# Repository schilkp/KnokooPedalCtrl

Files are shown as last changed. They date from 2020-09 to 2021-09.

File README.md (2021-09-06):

# KnokooPedalCtrl

A small modification that allows the Knokoo FES150 Fume Extractor to be turned on
and off using a 1/4" foot pedal.

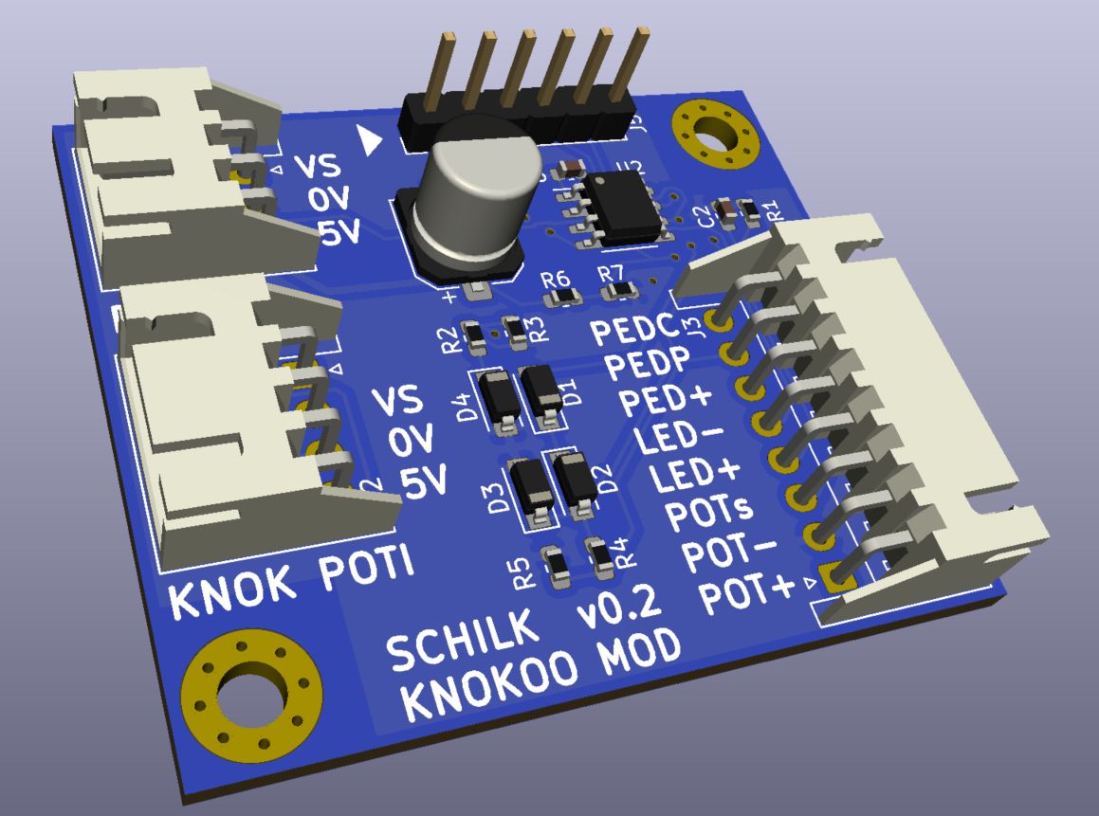
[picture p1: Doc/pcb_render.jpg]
PCB render


## Why?

The way my bench is setup, I cannot comfortably reach the speed control/power knob.
Life's very difficult, tell me about it. 

But because I know myself well enough to know that I won't use this (or any) fume extractor
if I have to crawl on the floor every time I want to solder something, this small project
was born.

It is also not the quietest machine, so being able to turn it on and off only when actually 
soldering has made using it much more pleasant. 

## How?

This small PIC12F1572-based board sits between the Knokoo's Main PCB and the front intensity knob.  

The Knokoo turns itself off when the intensity knob is turned all the way off.
This board interrupts the 5V rail normally provided to the potentiometer by the Knokoo PCB, and only
enables it when the foot pedal is pressed.

This way the Intensity Knob can permanently be left set to the desired intensity, and the pedal can
be used to turn the unit on and off. 

Pressing the pedal once turns the unit on and starts a timer controlled by the position of a second
potentiometer. The unit will shut off when either the timer runs out or the pedal is pressed again.

Pressing the pedal twice in short succession turns the unit on permanently until the pedal is pressed
again.

If the pedal is unplugged, the board will disable itself and the unit will function as before.

## Installation

[will follow shortly]

## Slight Modifications

### No Timer Potentiometer

Instead of a second potentiometer, the timer duration can also be permanently fixed using resistors R6 and R7.  

The duration will be approx `(15)*(R6/(R6+R7)` minutes

(R6+R7) should be 10K at least. The pins where the potentiometer would otherwise be connected to should be left disconnected.

### No Pedal Detect

If the jack for the pedal does not have a switch, PEDC should be connected to GND (for example to POT-).

Of course, in this case, the unit will not return to normal operation when no pedal is connected.

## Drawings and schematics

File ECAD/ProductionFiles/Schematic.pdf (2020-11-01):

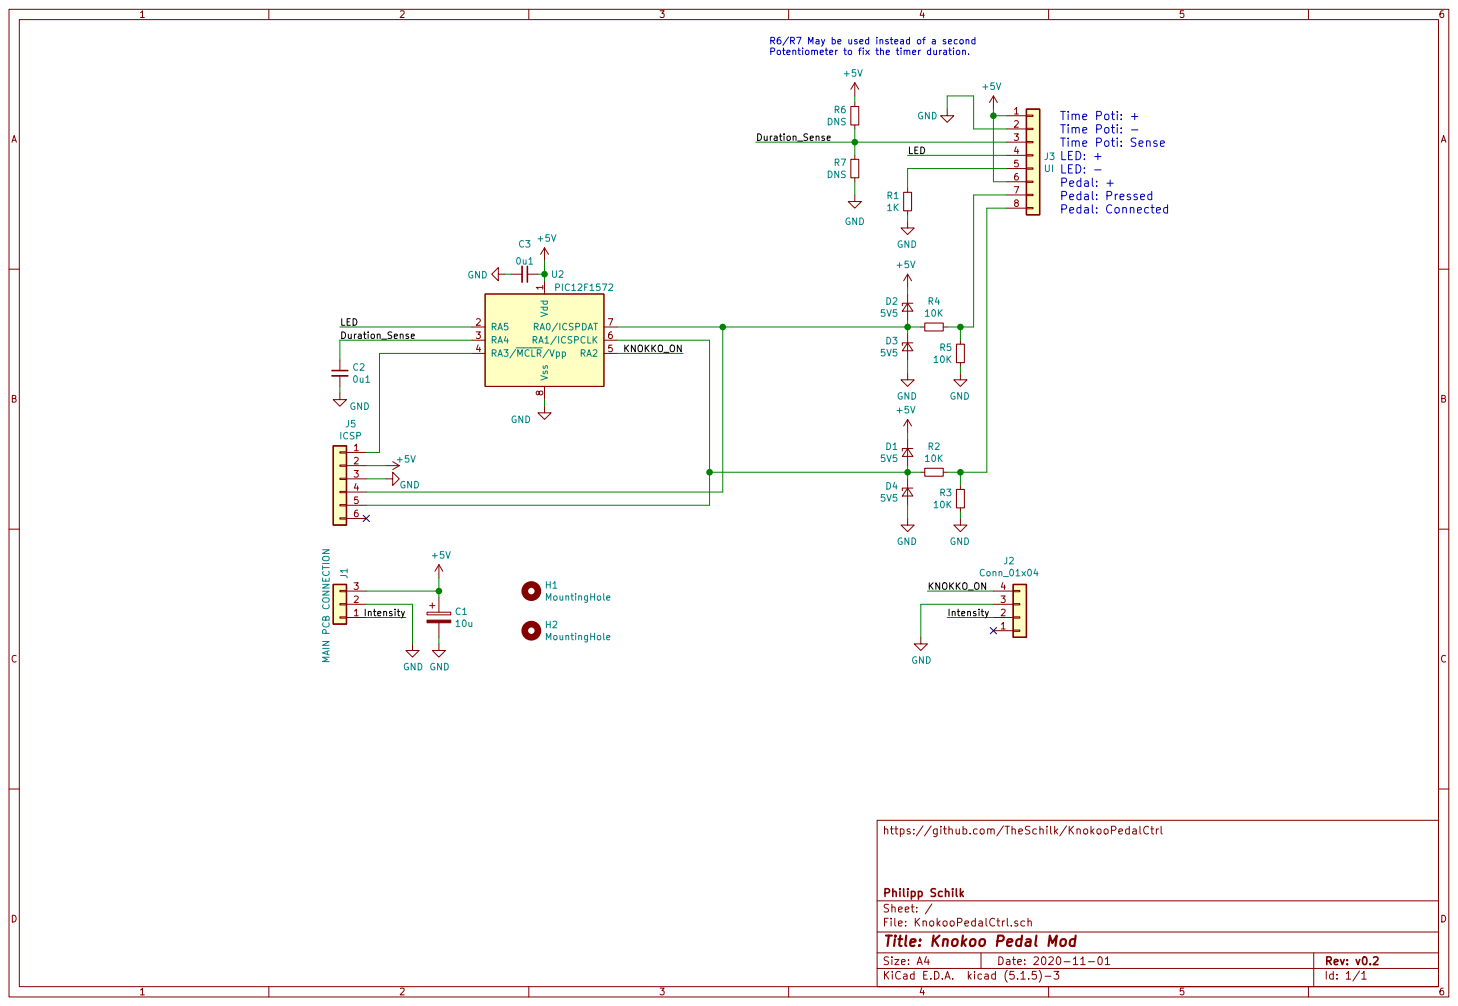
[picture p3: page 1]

https://github.com/TheSchilk/KnokooPedalCtrl

File: KnokooPedalCtrl.sch Sheet: / Philipp Schilk

Id: 1/1 Title: Knokoo Pedal Mod

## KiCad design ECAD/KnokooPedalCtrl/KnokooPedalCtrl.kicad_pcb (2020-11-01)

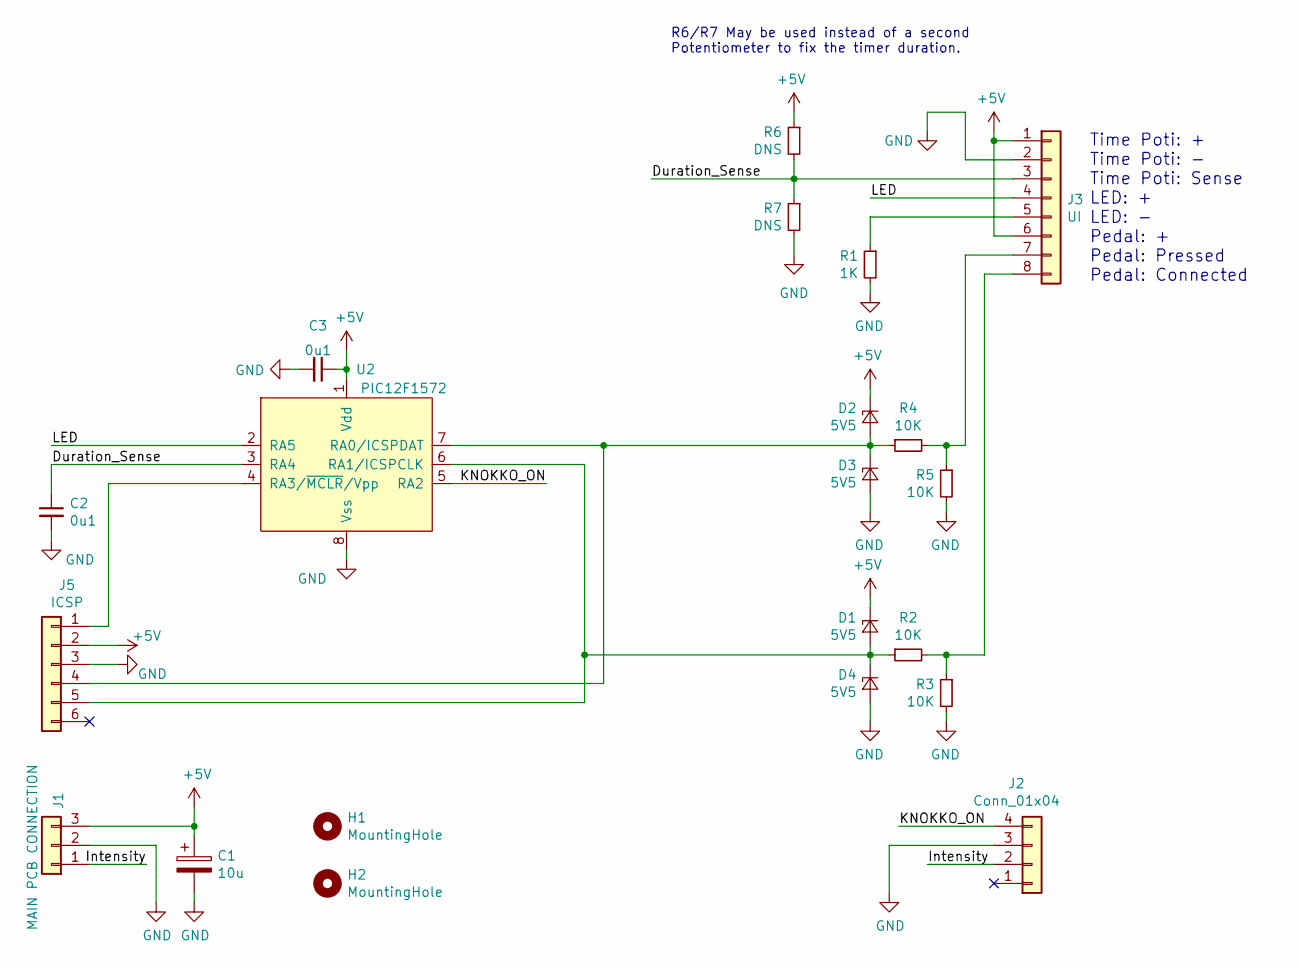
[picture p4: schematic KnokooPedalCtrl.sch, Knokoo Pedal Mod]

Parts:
C1: 10u; CP_Elec_6.3x7.7
C2, C3: 0u1; C_0603_1608Metric
D1, D2, D3, D4: 5V5; D_SOD-123
H1, H2: MountingHole; MountingHole_3.2mm_M3_Pad_Via
J1: MAIN PCB CONNECTION; JST_XH_S3B-XH-A_1x03_P2.50mm_Horizontal
J2: Conn_01x04; JST_XH_S4B-XH-A_1x04_P2.50mm_Horizontal
J3: UI; JST_XH_S8B-XH-A_1x08_P2.50mm_Horizontal
J5: ICSP; PinHeader_1x06_P2.54mm_Vertical
R1: 1K; R_0603_1608Metric
R2, R3, R4, R5: 10K; R_0603_1608Metric
R6, R7: DNS; R_0603_1608Metric
U2: PIC12F1572; SOIC-8_3.9x4.9mm_P1.27mm

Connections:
+5V: C1.1, C3.1, D1.1 (K), D2.1 (K), J1.3, J3.1, J3.6, J5.2, R6.1, U2.1 (Vdd)
/Duration_Sense: C2.1, J3.3, R6.2, R7.1, U2.3 (RA4)
/Intensity: J1.1, J2.2
/KNOKKO_ON: J2.4, U2.5 (RA2)
/LED: J3.4, U2.2 (RA5)
GND: C1.2, C2.2, C3.2, D3.2 (A), D4.2 (A), J1.2, J2.3, J3.2, J5.3, R1.2, R3.2, R5.2, R7.2, U2.8 (Vss)
unnamed: D1.2 (A), D4.1 (K), J5.5, R2.1, U2.6 (RA1/ICSPCLK)
unnamed: D2.2 (A), D3.1 (K), J5.4, R4.1, U2.7 (RA0/ICSPDAT)
unnamed: J3.5, R1.1
unnamed: J3.7, R4.2, R5.1
unnamed: J3.8, R2.2, R3.1
unnamed: J5.1, U2.4 (RA3/~MCLR~/Vpp)

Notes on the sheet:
Time Poti: + Time Poti: - Time Poti: Sense LED: + LED: - Pedal: + Pedal: Pressed Pedal: Connected
R6/R7 May be used instead of a second Potentiometer to fix the timer duration.

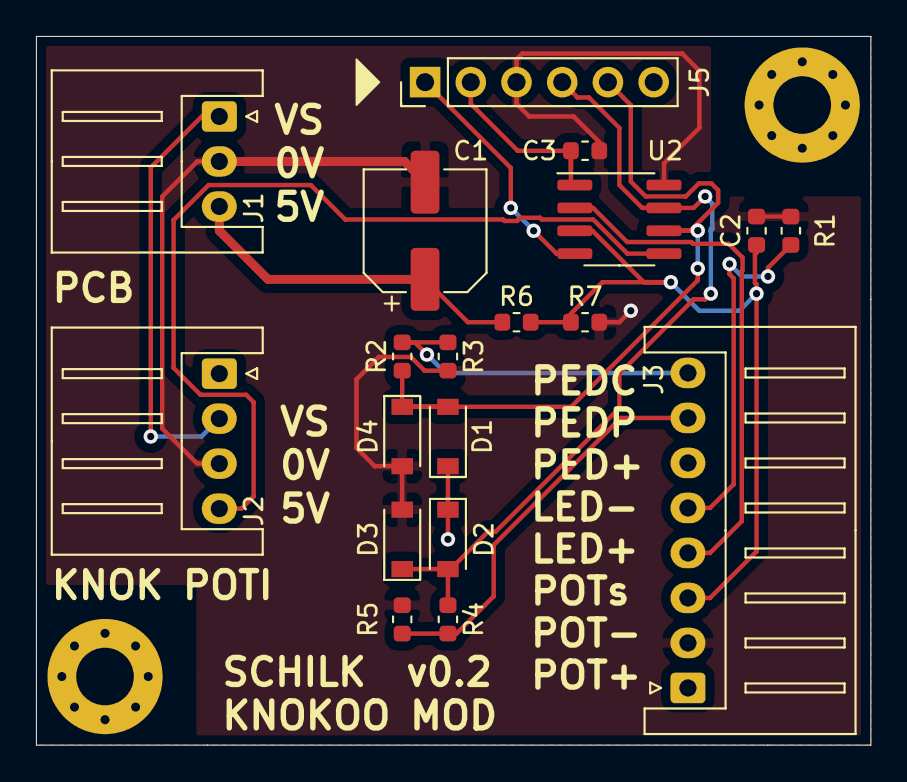
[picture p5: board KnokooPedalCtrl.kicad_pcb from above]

Board: 2 copper layers, 46.4 x 39.4 mm, 21 parts (0 on the bottom side), 12 nets.

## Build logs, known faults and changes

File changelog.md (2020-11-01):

# v0.2
  - Fixed Silkscreen of Poti Connector...
  - Added Resistors to bypass second potentiometer

# v0.1
  - Fixed pinorder of Knokoo Poti Connector
  - Fixed Silkscreen of PCB Connector

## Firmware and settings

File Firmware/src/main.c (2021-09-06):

// =================================================================
//                  Knokoo FES150 Pedal Control
//                      PIC12F1572 Firmware
//                      Philipp Schilk 2020
//
// This was written fairly quickly without much second thought.
// Please don't look to closely.
// =================================================================


// ======== PIC Fuses ==========================================================

// CONFIG1
#pragma config FOSC = INTOSC    // (INTOSC oscillator; I/O function on CLKIN pin)
#pragma config WDTE = ON        // Watchdog Timer Enable (WDT enabled)
#pragma config PWRTE = OFF      // Power-up Timer Enable (PWRT disabled)
#pragma config MCLRE = ON       // MCLR Pin Function Select (MCLR/VPP pin function is MCLR)
#pragma config CP = OFF         // Flash Program Memory Code Protection (Program memory code protection is disabled)
#pragma config BOREN = ON       // Brown-out Reset Enable (Brown-out Reset enabled)
#pragma config CLKOUTEN = OFF   // Clock Out Enable (CLKOUT function is disabled. I/O or oscillator function on the CLKOUT pin)

// CONFIG2
#pragma config WRT = OFF        // Flash Memory Self-Write Protection (Write protection off)
#pragma config PLLEN = OFF      // PLL Enable (4x PLL disabled)
#pragma config STVREN = ON      // Stack Overflow/Underflow Reset Enable (Stack Overflow or Underflow will cause a Reset)
#pragma config BORV = LO        // Brown-out Reset Voltage Selection (Brown-out Reset Voltage (Vbor), low trip point selected.)
#pragma config LPBOREN = OFF    // Low Power Brown-out Reset enable bit (LPBOR is disabled)
#pragma config LVP = ON         // Low-Voltage Programming Enable (Low-voltage programming enabled)


// ======== Config =============================================================

#define DEBOUNCE_TIME  25  // Time inputs are ignored after input in 10s of ms
#define DBLPRESS_TIME  400 // Max interval to count as 'double press' in 10s of ms
#define BLINK_TIME     100 // LED Blink period in 10s of ms

// Coefficients to determine min and max length:
// Min length in seconds: ADCSCALE_BASE / 100
// Max length in seconds: (ADCSCALE_BASE + ADCSCALE_MULT*2^10) / 100
#define ADCSCALE_MULT 90
#define ADCSCALE_BASE 12000

// ======== Code ===============================================================

#include <pic.h>
#include <stdint.h>

uint32_t debounce_count;
uint8_t debounce_prevstate;

uint32_t on_timer;
uint32_t press_timer;

uint32_t blink_timer;
uint8_t  blink_state;

uint32_t result;

typedef enum{
    state_off,
    state_timer,
    state_on         
}STATE_T;

STATE_T state;

int main(int argc, char** argv) {
    CLRWDT();
    
    // ===== WDT & CLK =====
    // Using internal MF OSC at 500khz
    OSCCONbits.SPLLEN = 0;
    OSCCONbits.IRCF = 0b0111;
    OSCCONbits.SCS = 0b10;
    
    // Have WDT reset every 512ms
    WDTCONbits.WDTPS = 0b01001;
    
    // ===== Config GPIO =====
    TRISAbits.TRISA0 = 1; // Pedal Input
    TRISAbits.TRISA1 = 1; // Pedal Sense Input
    TRISAbits.TRISA2 = 0; // KNOKOO Ouput
    TRISAbits.TRISA4 = 1; // Poti Input
    TRISAbits.TRISA5 = 0; // LED Output
    
    // Clear all outputs
    LATA = 0x0; 
    
    // Set RA4 as only analog input
    ANSELA = 0x0;
    ANSELAbits.ANSA4 = 1;
    
    // Disable all pullups, all pins push-pull,
    // no slewrate limiting
    WPUA = 0x0;
    ODCONA = 0x0;
    SLRCONA = 0x0;
    
    // ===== Config ADC ======
    ADCON0bits.CHS = 0b00011; // Select CH3 (RA4)
    
    ADCON1bits.ADFM = 1; // Right-justified result
    ADCON1bits.ADCS = 0b000; // Conversion Clk Fosc/2
    ADCON1bits.ADPREF = 0b00; // VDD is positive voltage refernce
    
    ADCON2bits.TRIGSEL = 0; // No Automatic triggering
    
    ADCON0bits.ADON = 1; // Turn on ADC
    
    ADCON0bits.GO = 1; // Start conversion
    
    // ===== Setup Variables =====
    debounce_count = 0;
    debounce_prevstate = PORTAbits.RA0;
    state = state_off;
    blink_state = 0;
    
    // ===== Config Regular interrupt =====
    // Setup Timer 0 to overflow at aprox. 120Hz and trigger interrupt
    OPTION_REGbits.TMR0CS = 0; // Timer 0 clocked from Fosc/4
    OPTION_REGbits.PSA = 0;    // Timer 0 has prescalar
    OPTION_REGbits.PS = 0b01;  // Timer 0 prescalar is /4
    
    INTCONbits.GIE = 1;    // Interupts enabled.
    INTCONbits.TMR0IE = 1; // Timer 0 interrupt enabled
    
    while(1){
        NOP();
    }
    return (EXIT_SUCCESS);
}

void UI(uint8_t did_press){
    // If you close your eyes, you can't see this mess of a state machine.
    switch(state){
        case state_off:
            LATAbits.LATA2 = 0;
            LATAbits.LATA5 = 0;
            
            if(did_press){
                // Go to timer state.
                state = state_timer;
                
                // Start timer
                on_timer = ADCSCALE_BASE+(ADCSCALE_MULT*result);
                
                // Reset Blinking
                blink_state = 1;
                blink_timer = BLINK_TIME;
                
                // Start double-press timer
                press_timer = DBLPRESS_TIME;
            }
            break;

        case state_timer:
            
            LATAbits.LATA2 = 1;
            LATAbits.LATA5 = blink_state;
            
            if(blink_timer == 0){
                blink_timer = BLINK_TIME;
                
                blink_state = (blink_state) ? 0 : 1;    
            } else {
                blink_timer--;
            }
            
            if(did_press){
                if(press_timer == 0){
                    // Turn off
                    state = state_off;
                    break;
                } else {
                    // Go to always on
                    state = state_on;
                    break;
                }
            }
            
            if(on_timer == 0){
                state = state_off;
                break;
            } else {
                on_timer--;
            }
            
            if(press_timer != 0){
                press_timer--;
            }
            break;
            
        case state_on:
            
            PORTAbits.RA2 = 1;
            PORTAbits.RA5 = 1;
            
            if(did_press){
                state = state_off;
            }
            
            break;
        default:
            state = state_off;
    }

}

void __interrupt() ISR(void){
    CLRWDT(); // pet the watchdog..
    
    // Handle ADC
    if(!ADCON0bits.GO_nDONE){
        // ADC Conversion finished
        result = (ADRESH << 8) | ADRESL;
        
        // Start next conversion
        ADCON0bits.GO_nDONE = 1;
    }
    
    uint8_t did_press = 0;
    
	// Handle De-bounce
	if(debounce_count == 0){ // Ready for next event
        // Determine if input changed and we should time out again
        if(debounce_prevstate != PORTAbits.RA0){
            debounce_count = DEBOUNCE_TIME;
            debounce_prevstate = PORTAbits.RA0;
            
            if(PORTAbits.RA0){
                did_press = 1;
            }
        }
        
    } else { // Still timed out
        debounce_count--;
        did_press = 0;
    }
    
    // If there is a pedal connected, handle the UI
    if(!PORTAbits.RA1){
        UI(did_press);
    } else {
        // Otherwise, just power on all the time
        PORTAbits.RA2 = 1;
        PORTAbits.RA5 = 0;
    }
    
    // Clear flags and reset GIE
    INTCONbits.TMR0IF = 0;
    INTCONbits.GIE = 1;
}

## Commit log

2020-09-26 Added PCB v0.0
    [KnokooPedalCtrl-B_Cu.gbr, KnokooPedalCtrl-B_Mask.gbr, KnokooPedalCtrl-B_Paste.gbr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]
2020-10-17 v0.1
    Small pinout and silkscreen fixes
    [KnokooPedalCtrl-B_Cu.gbr, KnokooPedalCtrl-B_Mask.gbr, KnokooPedalCtrl-B_Paste.gbr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]
